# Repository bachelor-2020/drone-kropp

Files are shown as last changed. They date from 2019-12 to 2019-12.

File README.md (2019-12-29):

# Lego drone chassis

This is a parametric and customizable drone chassis, made of some custom 3D printed parts and lego. It is built with the main goal of being modular and reconfigurable. The drone uses an RPI 3 B+ and an Emlid Navio2 as flight controller, but could easily be modified to accept any type of flight controller. It will also include optional mounting parts for among other things Arduino Uno, Grid-EYE thermal sensor, Intel RealSense stereo camera.

## Prerequisites
To use the project you will need these prerequisites:

### Software
 - OpenSCAD
 - A slicer and 3D printing software

### Hardware
 - 3D printer
 - Raspberry Pi 2 B or better
 - Emlid Navio2 or other flight controller
 - Drone motors and ESCs
 - Propellers
 - Lego beams and pins

#### Optional
 - Radio receiver and transmitter (for manual control)
 - Intel RealSense stereo camera (for obstacle detection and mapping)
 - Lidar (for obstacle detection and mapping)
 - Grid-EYE thermal sensor

## Configuring
Configuration is done through the main configuration file `config/main_config.scad`. Change parameters in this file as needed.

## Previewing
To preview the assembled drone chassis, open `assembly.scad` and render it.

## Exporting the parts for print
Exporting the parts for print is for the moment a manual process. It involves creating a new scad file,  or modifying `assembly.scad` to only show the part you want to export, then rendering and exporting the part as stl. This process will hopefully become more user friendly in the future. There are plans to make an automated process for this.

## Assembling
To assemble the drone after printing the parts, please see `assembly.scad` and try to assemble the parts to match the preview. Some lego parts are required, but most can be printed if necessary.

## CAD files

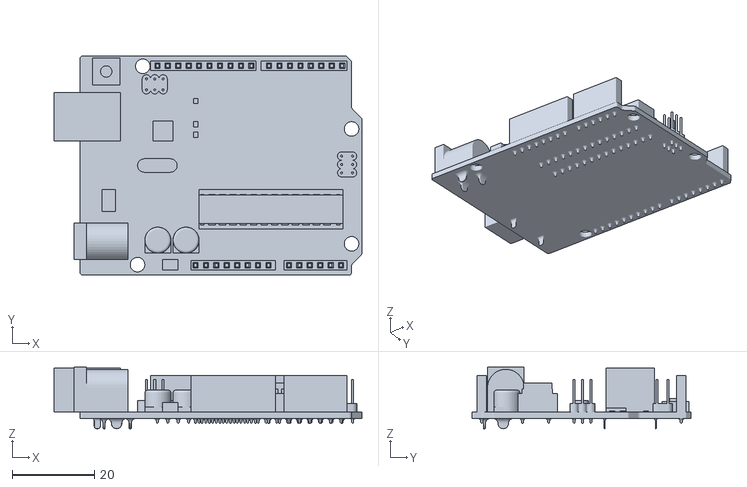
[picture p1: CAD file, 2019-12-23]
arduino/arduino.stl
74.9 x 53.3 x 15.0

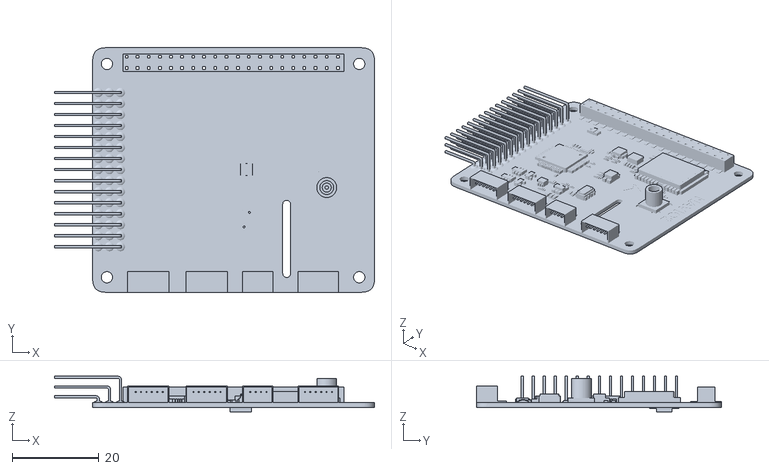
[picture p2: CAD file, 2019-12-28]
rpi/navio2.stl
73.8 x 56.4 x 8.20

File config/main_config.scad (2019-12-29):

// --------------------------------------------------
//
// User parameters:
//
// --------------------------------------------------

PLACEHOLDERS = false;
LOWRES = true;

// Battery dimensions
BATTERY_SIZE = [208, 73, 25];


// There are 3 different types of arms available:
//``````````````````````````````````````````````
// Type 1:
//              _____
// O-----------|     |-----------O
//             |     |
//
// Type 2:
//              _____
// O===========|     |===========O
//             |     |
//
//Type 3:
//              _____
// O-----------|     |-----------O
//  ``''**~..,,|     |,,..~**''´´

ARM_TYPE = 1;
ARM_LENGTH = 21; // Arm length in number of lego holes


// Motor mount
MOTOR_SCREW_DIA = 3;
MOTOR_SCREW_DISTANCE_MIN = 12;
MOTOR_SCREW_DISTANCE_MAX = 19;

// Landing gear
LANDING_LENGTH = 3; // Landing gear length (height?) in number of lego holes


// --------------------------------------------------
//
// DO NOT EDIT BELOW THIS LINE:
//
// --------------------------------------------------

$fn = LOWRES ? 14 : 100;

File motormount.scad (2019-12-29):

include <config/main_config.scad>
include <lego/lego.scad>;

// Arm bracket is the part of motormount that the arm screws into
module armbracket(){
	difference(){
		translate([-1.5*beamw, 0, 0]) cube([3*beamw, beamw, beamh]);
		translate([5, 2.5, 0]*u) studhole();
		translate([0, 2.5, 0]*u) studhole();
		translate([-5, 2.5, 0]*u) studhole();
	}
}


// Motor bracket is the part of motormount that motor screws into
module motorbracket(inner=MOTOR_SCREW_DISTANCE_MIN, outer=MOTOR_SCREW_DISTANCE_MAX, screwdia=MOTOR_SCREW_DIA){

	// Screwholes
	module screwhole(dia, length){
		cylinder (length, dia*1.1/2, dia*1.1/2);
	}

	thickness = 3;
	r = (outer/2 + screwdia)*1.05;
	translate([0, r-2, 0]){
		difference(){

			// Main body of motor bracket
			cylinder(thickness, r, r);

			// Motor mounting slots
			for (d = [0 : 90 : 360]){
				rotate ([0, 0, d+45])
				hull(){
					translate ([inner/2, 0, 0])
						screwhole(screwdia, thickness);
					translate ([outer/2, 0, 0])
						screwhole(screwdia, thickness);
				}
			}

			// Cutoff for arm mount
			translate([-r, -r, 0])
				cube([r*2, 2, thickness]);

		}

		// Motor placeholder model
		if (PLACEHOLDERS)
			#mirror([0, 0, 1])
			import("EMAX_RSII_2206_2300kv.stl");
	}
}

// Motor mount is the whole part. This is the one that should be printed
module motormount(){
	motorbracket();

	rotate([90, 0, 90])
		translate([-beamw*1.5, 0, -beamw/2])
		armbracket();
}

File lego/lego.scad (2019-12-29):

u = 1.6; // One lego unit
play = 0.226*u; // Tolerance of holes
studr = 3*0.5*u; // Radius of stud/pin
beamh = 5*u;
beamw = 5*u;

ZEROISH = 0.000000000000001;

// Body of lego beam without holes
module beambody(length){
	translate([0, 0, beamh/2])
	minkowski() {
		cube([ZEROISH,
				length*5*u - beamw,
				beamh],
			center = true);
		cylinder(ZEROISH, beamw/2, beamw/2);
	}
}

// Cutouts for stud/pin holes in beams
module studhole(length=1){
	r = studr + play/2;
	insert_radius = 3.5*0.5*u + play;
	insert_height = 0.5*u + play/2;
	cylinder(beamh*length, r, r);

	if (!LOWRES)
	for (i = [0, beamh-insert_height]) {
		translate([0,0,i]) cylinder(insert_height, insert_radius, insert_radius);
	}
}


// Beam with holes
module beam(length) {
	difference(){
		translate([0, length*5*u/2, 0])
			beambody(length);
		for (i = [0 : length-1]) {
			pos = (2.5 + 5*i) * u;
			translate([0, pos, 0]) studhole();
		}
	}
}

// L shaped beam
module lbeam(length=4, width=3) {
	translate([0, -4, 0]) beam(length);
	rotate([0, 0, 90]) translate([0, -4, 0]) beam(width);
}

// C shaped beam
module cbeam(length=4, width=3) {
	translate([0, -4, 0]) beam(width);
	rotate([0, 0, 90]) translate([0, -4, 0]) beam(length);
	translate([(1-length)*5*u,0,0])
	translate([0, -4, 0]) beam(width);
}

// O shaped beam
module obeam(length=4, width=3) {
	translate([0, -4, 0]) beam(width);
	rotate([0, 0, 90]) translate([0, -4, 0]) beam(length);
	translate([0, -(1-width)*5*u, 0])
	rotate([0, 0, 90]) translate([0, -4, 0]) beam(length);
	translate([(1-length)*5*u,0,0])
	translate([0, -4, 0]) beam(width);
}

// F shaped beam
module fbeam(length=5, width=3) {
	translate([(1-length)*5*u,0,0])
	translate([0, -4, 0]) beam(width);
	rotate([0, 0, 90]) translate([0, -4, 0]) beam(length);
	translate([floor(1-length/2)*5*u,0,0])
	translate([0, -4, 0]) beam(width);
}

// E shaped beam
module ebeam(length=5, width=3) {
	translate([(1-length)*5*u,0,0])
	translate([0, -4, 0]) beam(width);
	rotate([0, 0, 90]) translate([0, -4, 0]) beam(length);
	translate([floor(1-length/2)*5*u,0,0])
	translate([0, -4, 0]) beam(width);
	translate([0, -4, 0]) beam(width);
}

// B shaped beam
module bbeam(length=5, width=3) {
	translate([(1-length)*5*u,0,0])
	translate([0, -4, 0]) beam(width);
	rotate([0, 0, 90]) translate([0, -4, 0]) beam(length);
	translate([0,-(1-width)*5*u,0])
	rotate([0, 0, 90]) translate([0, -4, 0]) beam(length);
	translate([floor(1-length/2)*5*u,0,0])
	translate([0, -4, 0]) beam(width);
	translate([0, -4, 0]) beam(width);
}

// H shaped beam
module hbeam(length=5, width=3) {
	rotate([0, 0, 90]) translate([0, -4, 0]) beam(length);
	translate([0,-(1-width)*5*u,0])
	rotate([0, 0, 90]) translate([0, -4, 0]) beam(length);
	translate([floor(1-length/2)*5*u,0,0])
	translate([0, -4, 0]) beam(width);
}

// Axle
module axle(length=2, hole=false) {
	a = hole ? u+play : u;
	b = hole ? 4.7+play : 4.7;
	translate([0, 0, length*beamw/2]) {
		cube([a, b, length*beamw], center=true);
		cube([b, a, length*beamw], center=true);
	}
}

// Cutout for axle holes
module axlehole(length=1) {
	axle(length, true);
}

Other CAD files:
assembly.scad
arduino/arduino.scad
chassis.scad
grideye/grideye.scad
rpi/RPI.scad

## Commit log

2019-12-17 Initial commit. Import lego stuff
    [lego.scad]
2019-12-17 Add comments
    [lego.scad]
2019-12-17 Rewrite studhole
    [lego.scad]
2019-12-17 Move lego to subdirectory
    [lego.scad]
2019-12-17 Readability overhaul
    [lego.scad]
2019-12-17 Fix tolerance for axle holes
    [lego.scad]
2019-12-17 Readability improvement
    [lego.scad]
2019-12-17 Rewrite axle hole logic
    [lego.scad]
2019-12-17 Fix studhole length
    [lego.scad]
2019-12-17 Fix stud hole tolerances
    [lego.scad]
2019-12-17 Remove test code from lego.scad
    [lego.scad]
2019-12-17 Start working on motormount
    [motormount.scad]
2019-12-17 Set default axlehole length
    [lego.scad]
2019-12-17 Add motor bracket to motormount
    [motormount.scad]
2019-12-18 Add rpi mount stl
    [rpi_mount.stl]
2019-12-18 First version of main body
    [main.scad]
2019-12-19 Doubledecker version
    [main.scad]
2019-12-19 Change motormount from lego axle to pin
    [motormount.scad]
2019-12-19 Refactor motormount
    [motormount.scad]
2019-12-19 Refactor arm mount placement
    [main.scad]
2019-12-19 Create RPI library with cutouts and placeholders
    [RPI.scad]
2019-12-19 Add padding to RPI cutout
    [RPI.scad]
2019-12-19 Fix centering of RPI placeholder
    [RPI.scad]
2019-12-19 Start work on new chassis type
    [chassis.scad]
2019-12-20 Refactor RPI.scad
    [RPI.scad]
2019-12-20 Clean up chassis.scad
    [chassis.scad]
2019-12-20 Move RPI stuff to subdirectory
    [RPI.scad, chassis.scad]
2019-12-20 Make important variables global
    [chassis.scad]
2019-12-20 Add arm mounts to chassis
    [chassis.scad]
2019-12-20 Add a lot of custom lego pieces
    [lego.scad]
2019-12-21 Fix path to rpi.stl
    [RPI.scad]
2019-12-21 Adjust chassis sizes
    [chassis.scad]
2019-12-21 Move arm brackets to rpi_mount_plate module
    [chassis.scad]
2019-12-21 Hollow out rpi mount plate
    [chassis.scad]
2019-12-21 Parameterize length of arm brackets
    [chassis.scad]
2019-12-21 Add module for arm plates
    [chassis.scad]
2019-12-21 Add module arm_bracket_double
    [chassis.scad]
2019-12-22 Make operator module place_on_corner
    [chassis.scad]
2019-12-22 Add distance parameter to place_on_corners
    [chassis.scad]
2019-12-22 Add option for arm bracket length
    [chassis.scad]
2019-12-22 Add assembly.scad, for fully assembled preview
    [assembly.scad, chassis.scad]
2019-12-23 Improve readability chassis.scad
    [chassis.scad]
2019-12-23 Add arduino.scad
    [arduino.scad]
2019-12-23 Add arduino mount plate
    [chassis.scad]
2019-12-23 Remove file for old type of chassis
    [main.scad]
2019-12-23 Fix arduino include in chassis.scad
    [chassis.scad]
2019-12-23 Remove debug highlighting in arduino.scad
    [arduino.scad]
2019-12-23 Add arduino model
    [arduino.scad, arduino.stl, chassis.scad]
2019-12-23 Fix arduino screwhole position
    [arduino.scad]
2019-12-23 Improve readability: assembly.scad
    [assembly.scad]
2019-12-24 Add step file for Nvidia Jetson
2019-12-26 Add models for Navio2 and Nvidia Jetson
    [navio2.stl]
2019-12-26 Remove step file in favour of stl
2019-12-26 Add Navio2 on top of RPI placeholder
    [RPI.scad]
2019-12-26 Flip Navio2 180 degrees
    [navio2.stl]
2019-12-27 Simplify and improve readability of motormount.scad
    [motormount.scad]
2019-12-27 Add comments to motormount.scad
    [motormount.scad]
2019-12-27 Clean up for loop in RPI.scad
    [RPI.scad]
2019-12-27 Add model of motor
2019-12-27 Refactor screwhole code in motor mounts
    [motormount.scad]
2019-12-27 Add variable for motor bracket thickness
    [motormount.scad]
2019-12-27 Add motor placeholder to motormount
    [motormount.scad]
2019-12-28 Fix rpi model
    [RPI.scad]
2019-12-28 Fix EMAX motor model
2019-12-28 Move translation from code to stl for Navio2
    [RPI.scad, navio2.stl]
2019-12-28 Remove old leftover rpi_mount.stl
    [rpi_mount.stl]
2019-12-28 Fix incorrectly labeled comment in assembly.scad
    [assembly.scad]
2019-12-28 Add mount for Grid-EYE thermal sensor
    [chassis.scad, grideye.scad]
2019-12-29 Refactor motormount.scad. Move motor model into motor bracket module
    [motormount.scad]
2019-12-29 Create main configuration file
    [assembly.scad, chassis.scad, lego.scad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]
